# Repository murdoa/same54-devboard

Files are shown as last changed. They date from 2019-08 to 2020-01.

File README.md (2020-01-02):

# SAM-E54 Development Board
### Summary 
Development Board based around the Atmel SAME54 MCU exposing peripherals such as USB Host/Device, USB Serial, 100BASE-T Ethernet, SDHC and a QSPI with 1Gb flash.
### Features
- USB Host / Device
- USB Serial (CP2102) 
- SDHC Interface
- 100BASE-T Ethernet (KSZ8091RNA PHY)
- QSPI with W25N01GV footprint (1Gb flash)
- Cortex M ISP header
- 4 Indicator LEDs
- 3 Push Button switches
- 43 Pins accessible through 60 pin header

## Finished Board
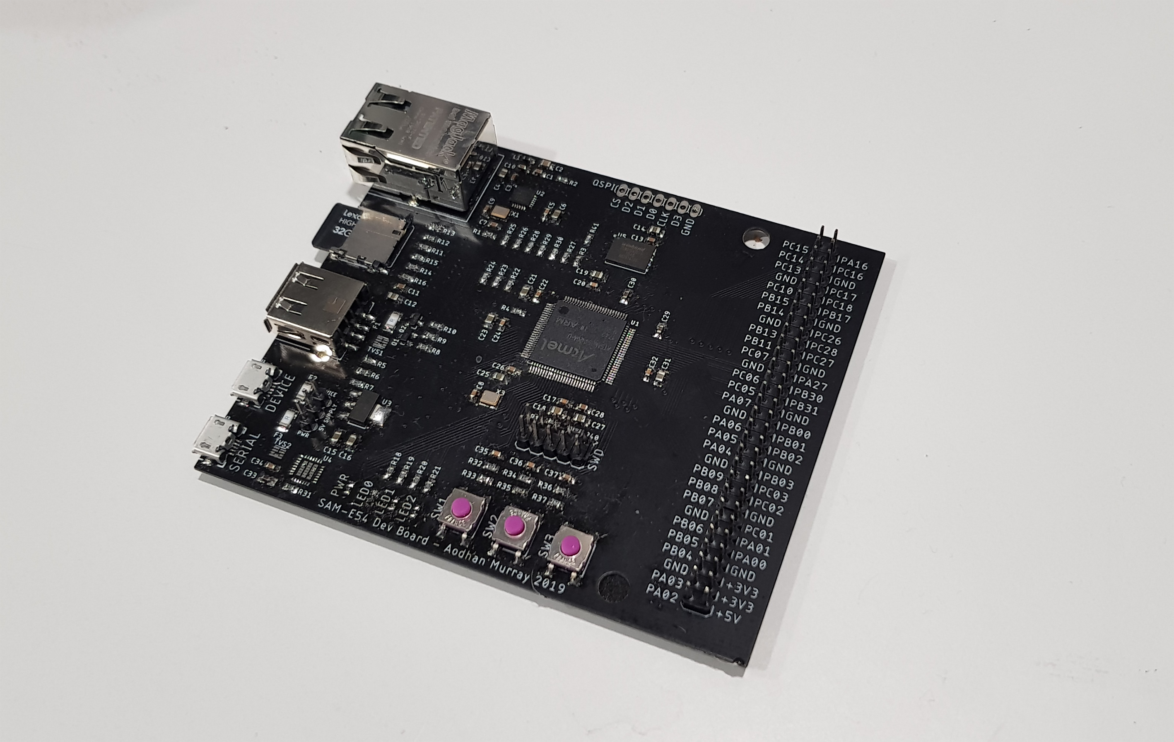
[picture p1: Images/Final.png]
Finished PCB Image


## PCB Stackup
| Layer | Material | Thickness |
|:-----:|:---:|:---:|
| 1 | Copper | 0.035mm |
|  | Prepreg | 0.2mm |
| 2 | Copper | 0.0175mm |
|  | Core | 0.265mm |
| 3 | Copper | 0.0175mm |
|  | Prepreg | 0.2mm |
| 4 | Copper | 0.035mm |

## Copper Layers
| Layer 1 | Layer 2 |
|:----:|:----:|
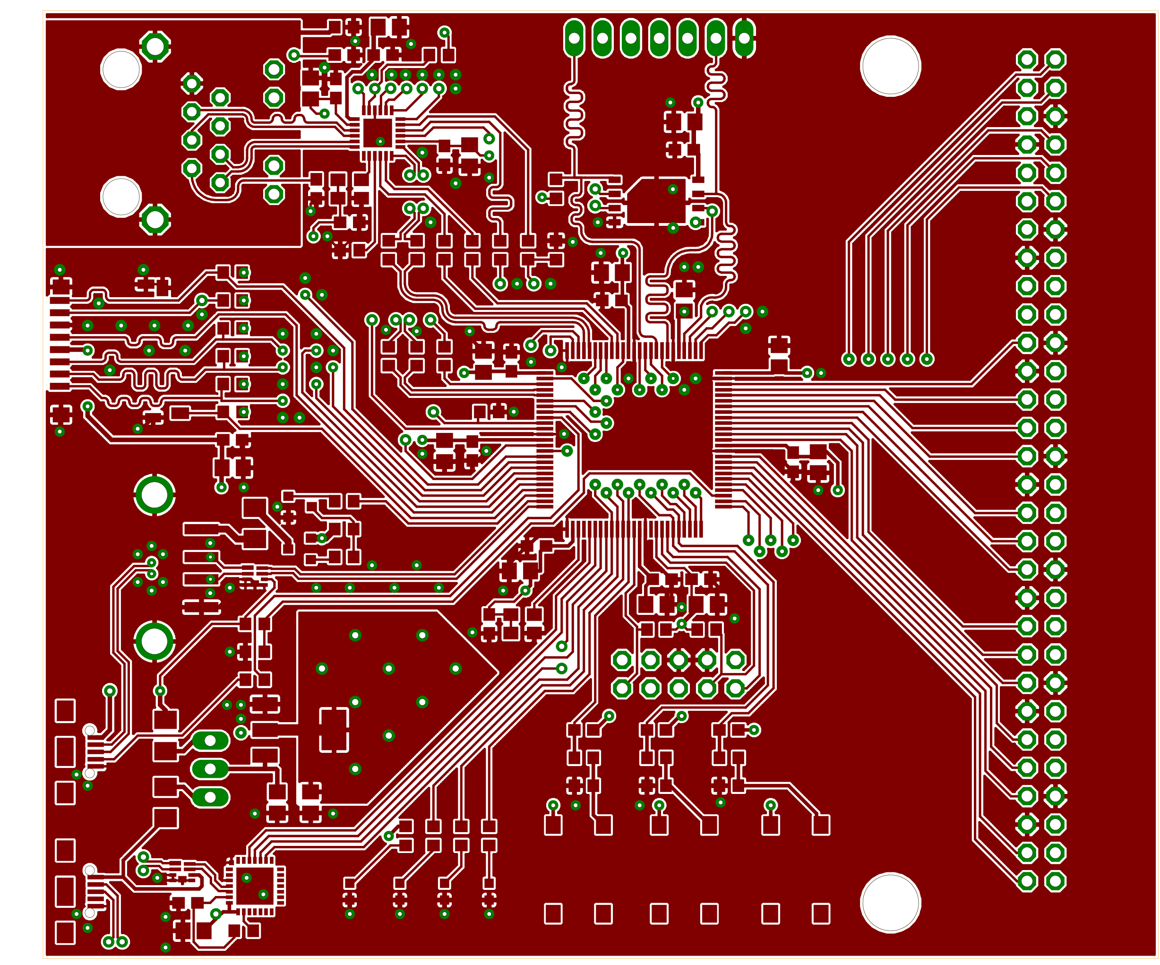
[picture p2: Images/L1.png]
Layer 1 Copper Image
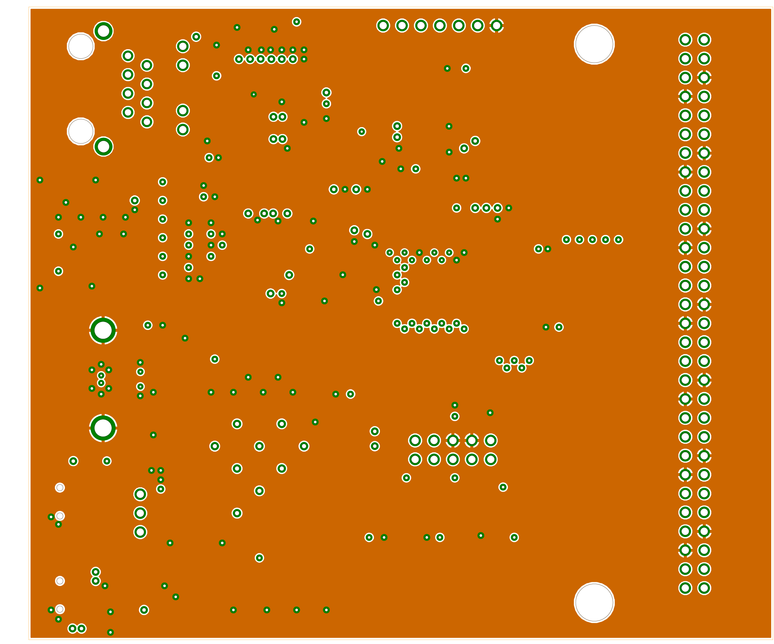
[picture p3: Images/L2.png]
Layer 2 Copper Image
||  |

| Layer 3 | Layer 4 |
|:----:|:----:|
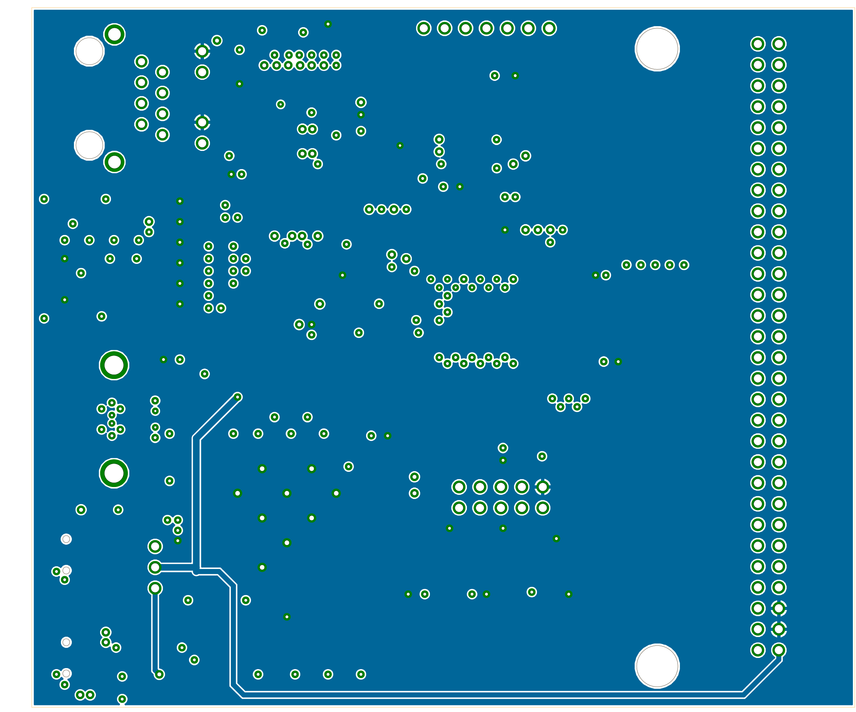
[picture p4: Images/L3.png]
Layer 3 Copper Image
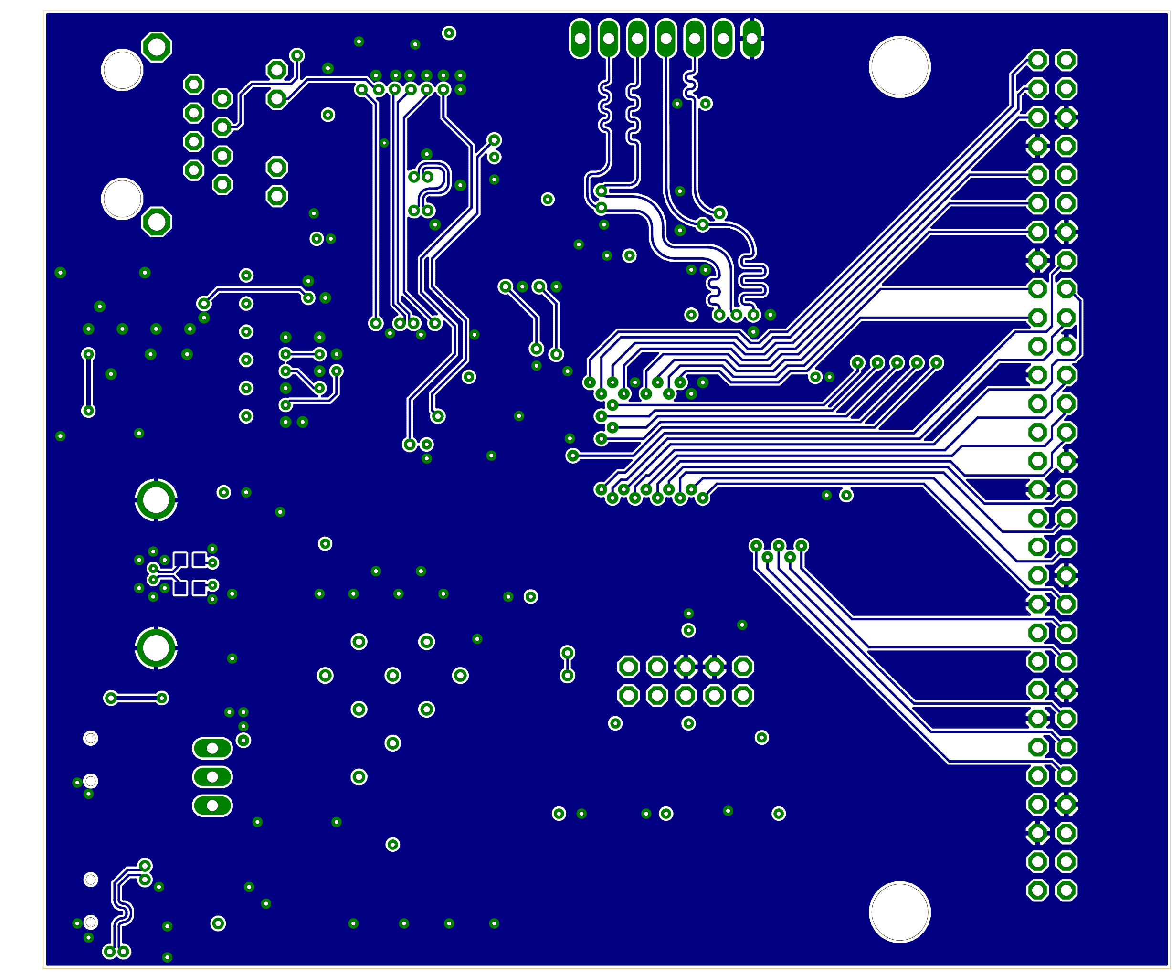
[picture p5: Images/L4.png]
Layer 4 Copper Image
||  |

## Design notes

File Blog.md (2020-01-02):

# ADS131E08 - Breakout

### Summary
Development Board based around the Atmel SAME54 MCU exposing peripherals such as USB Host/Device, USB Serial, 100BASE-T Ethernet, SDHC and a QSPI with 1Gb flash.

### Tags
 - EAGLE
 - Hardware Project
 - Development Board

### Images
 - [Images/Final.png] Final assembled PCB
 - [Images/FinishedDaughterBoard.png] Assembled ADC daughter board.

### Post 

### Features
- USB Host / Device
- USB Serial (CP2102) 
- SDHC Interface
- 100BASE-T Ethernet (KSZ8091RNA PHY)
- QSPI with W25N01GV footprint (1Gb flash)
- Cortex M ISP header
- 4 Indicator LEDs
- 3 Push Button switches
- 43 Pins accessible through 60 pin header

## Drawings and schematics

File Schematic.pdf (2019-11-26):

USB Power, ESD and OTG Host Detection | Push Buttons

# V_USB

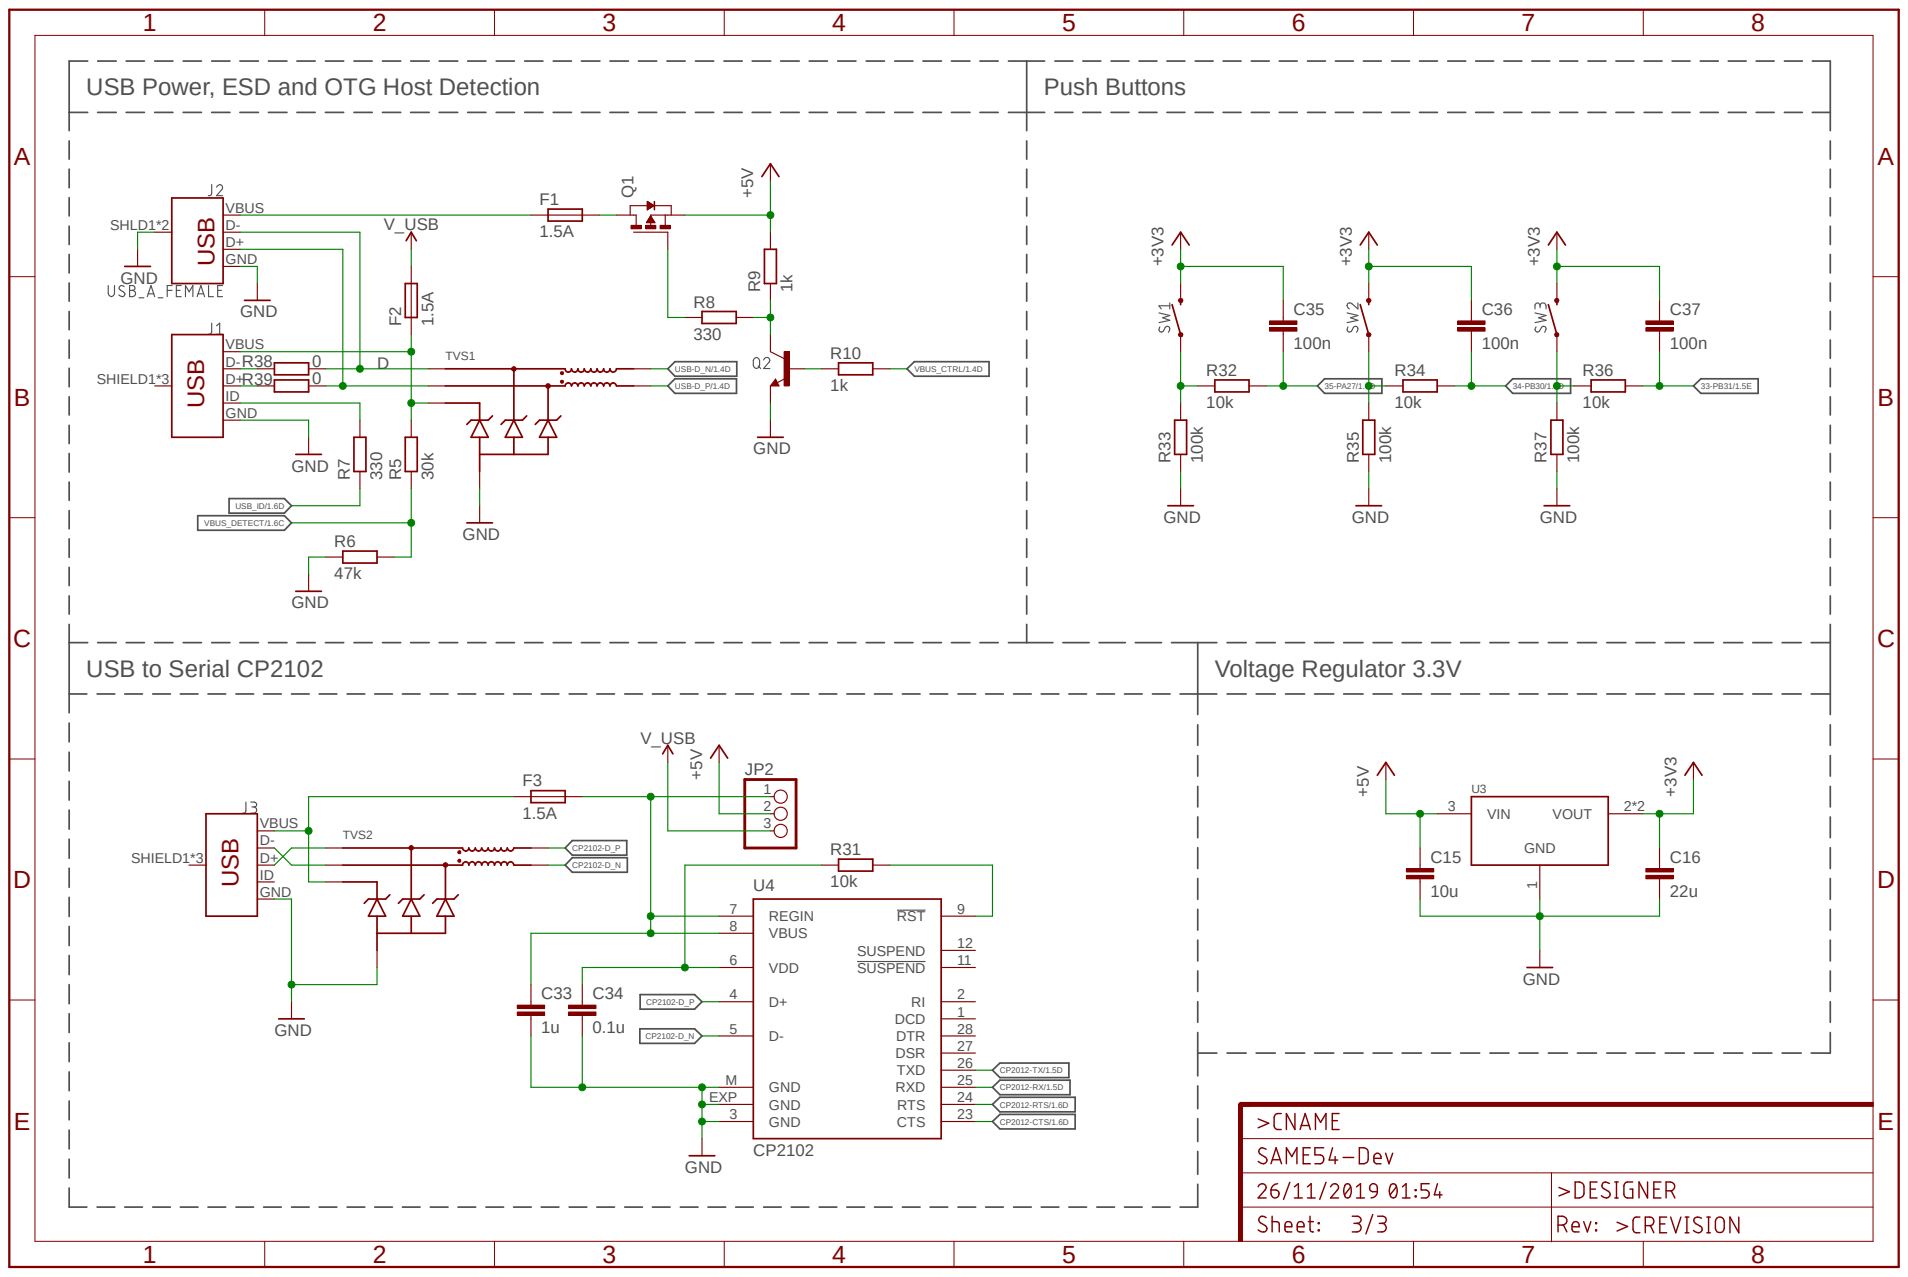
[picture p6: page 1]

CP2012-CTS/1.6D USB USB USB

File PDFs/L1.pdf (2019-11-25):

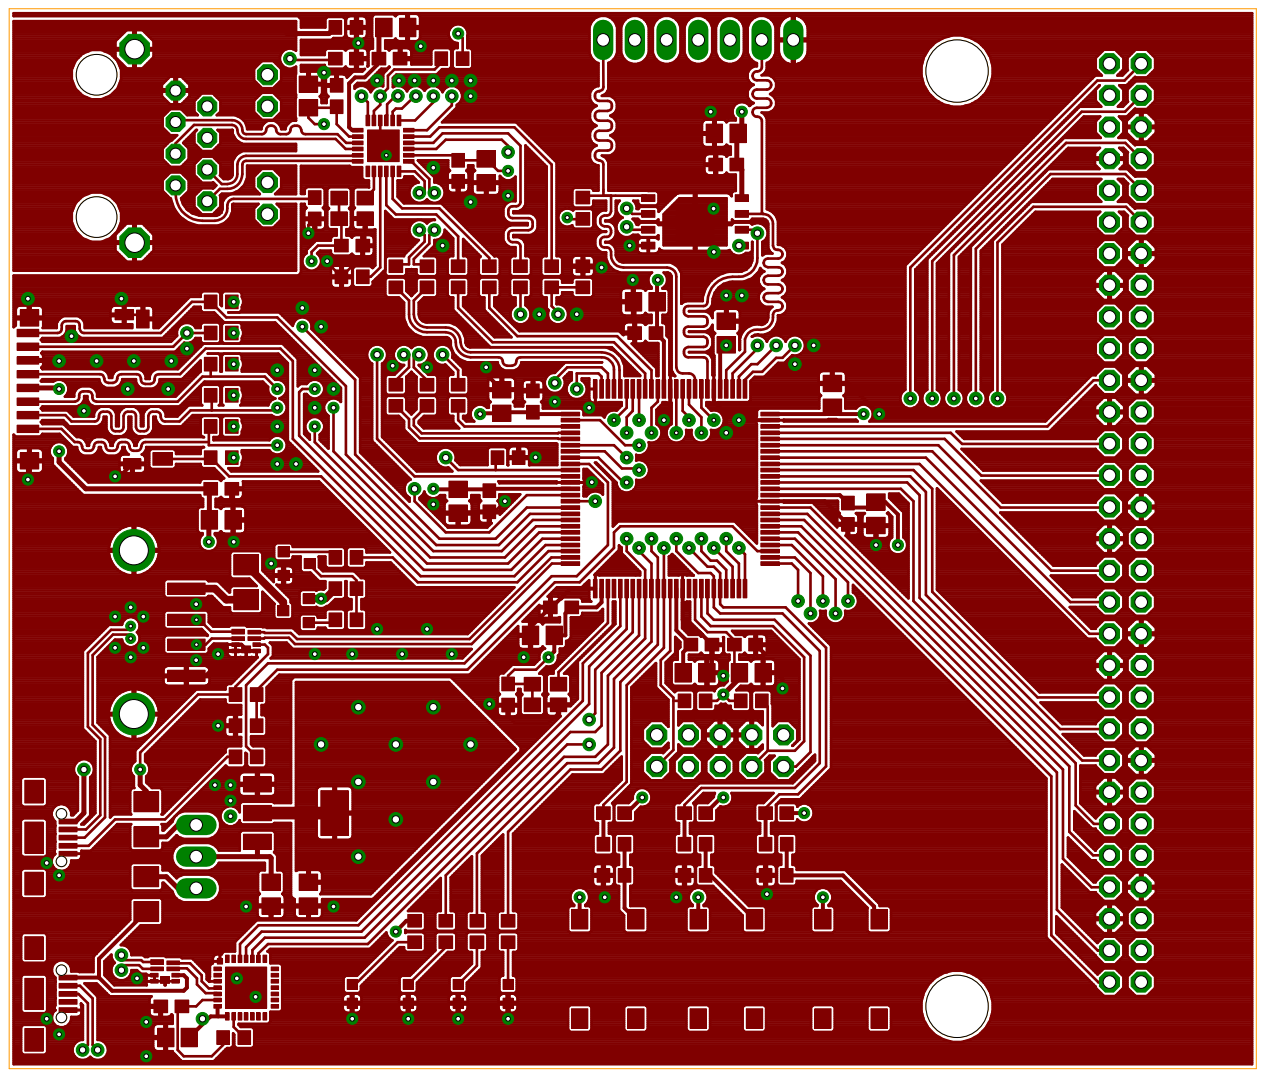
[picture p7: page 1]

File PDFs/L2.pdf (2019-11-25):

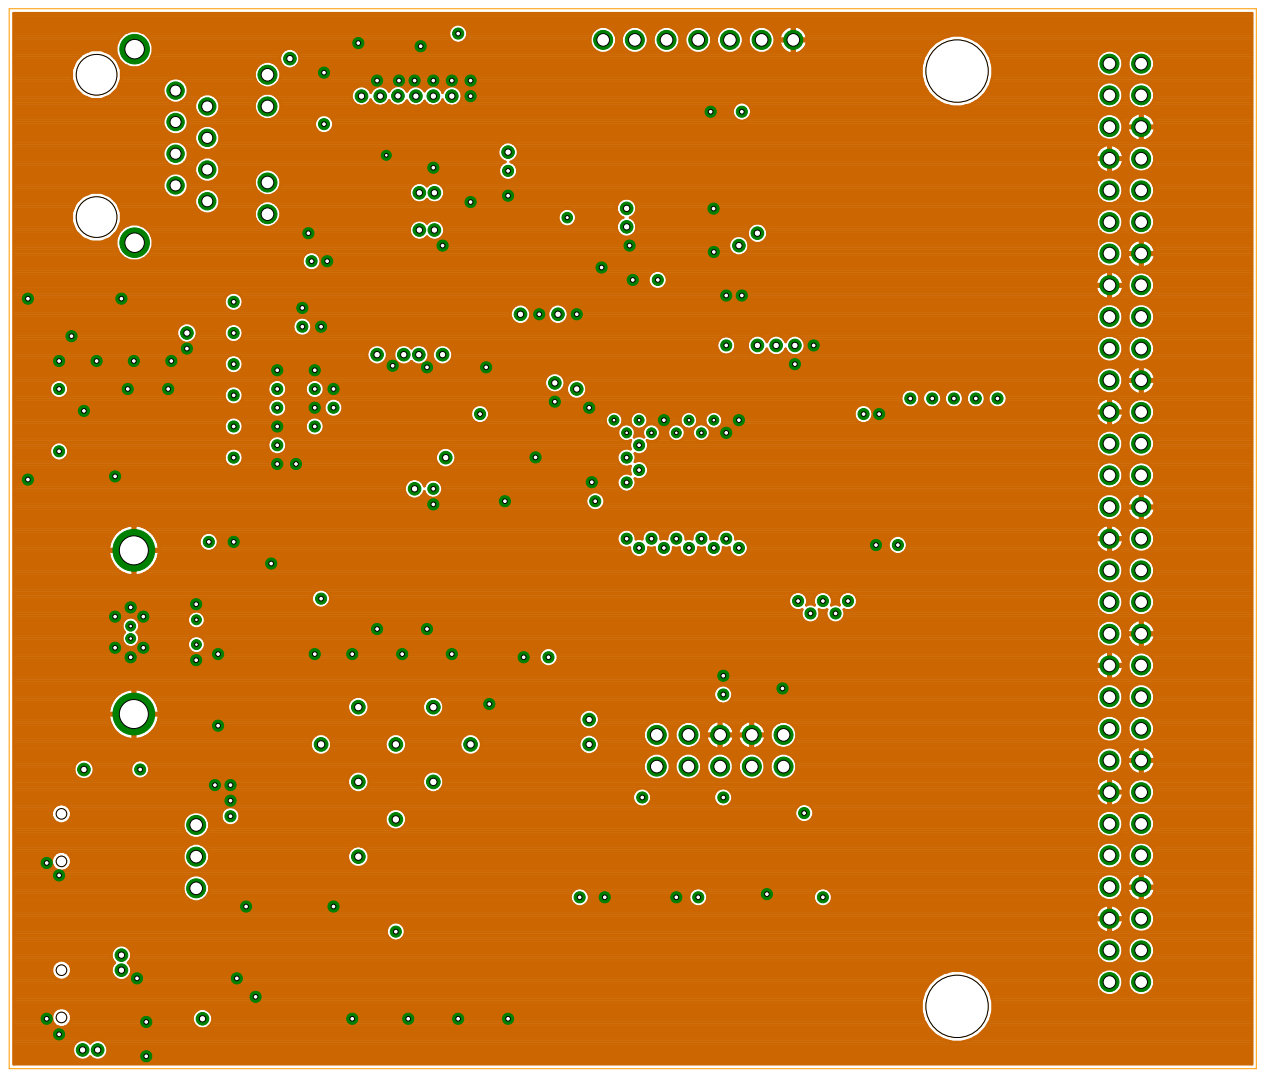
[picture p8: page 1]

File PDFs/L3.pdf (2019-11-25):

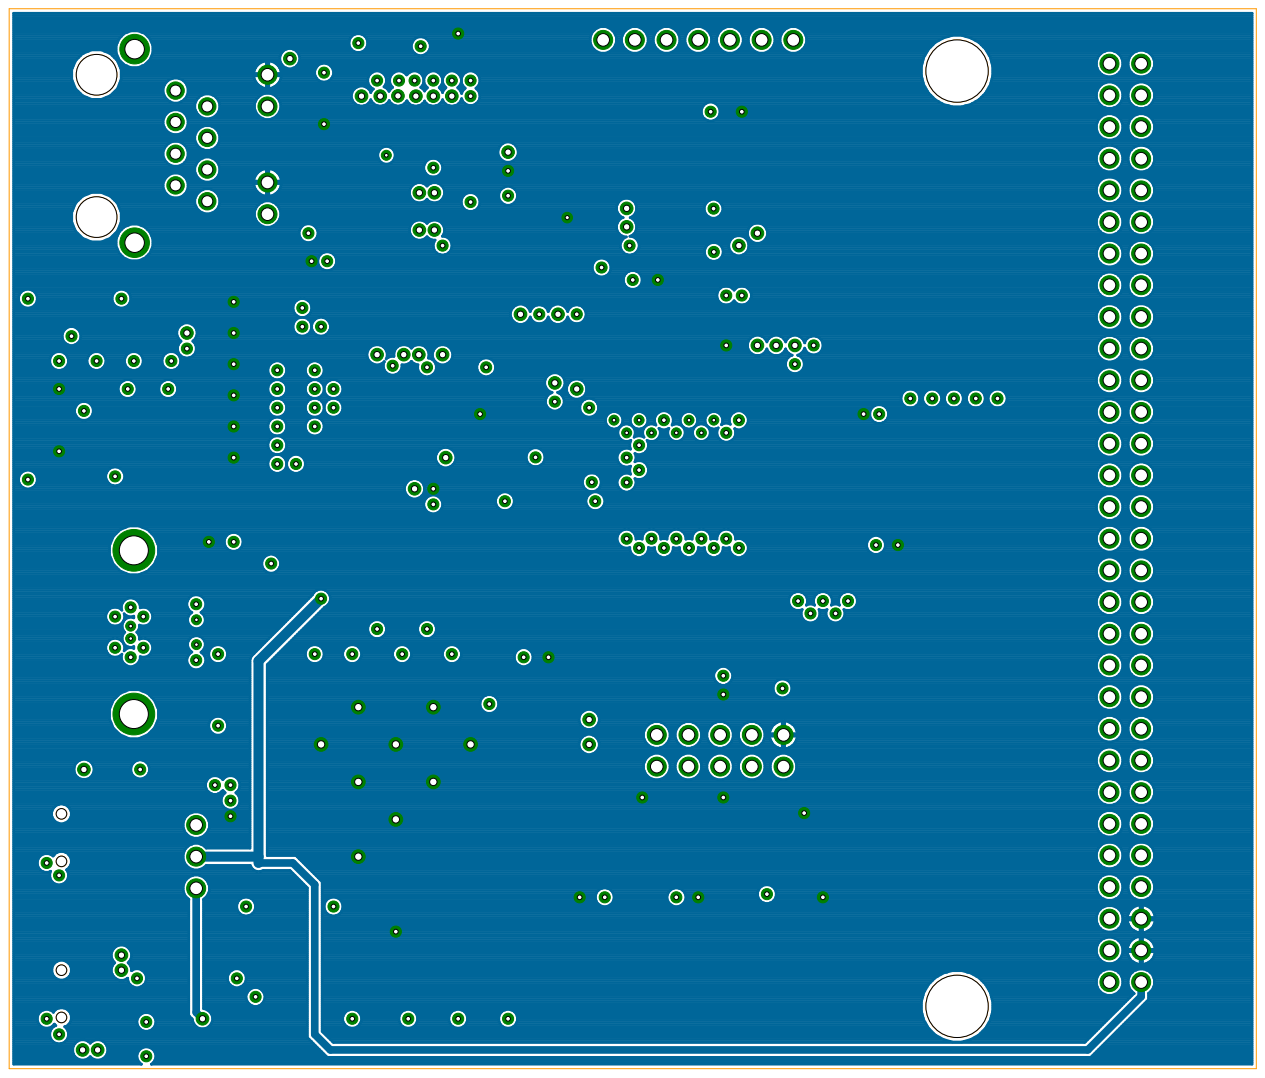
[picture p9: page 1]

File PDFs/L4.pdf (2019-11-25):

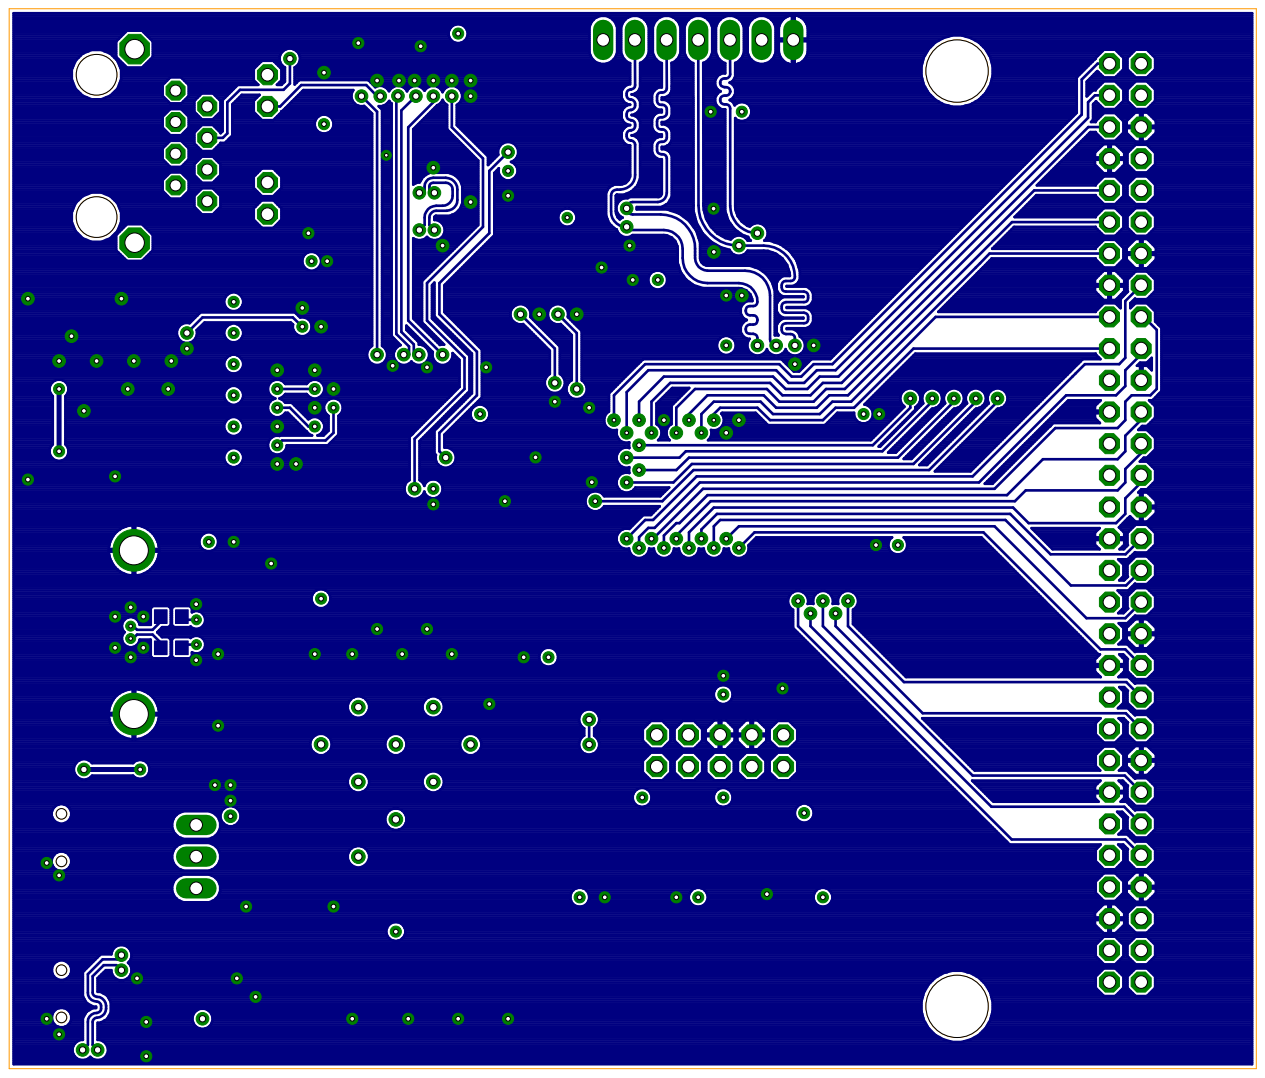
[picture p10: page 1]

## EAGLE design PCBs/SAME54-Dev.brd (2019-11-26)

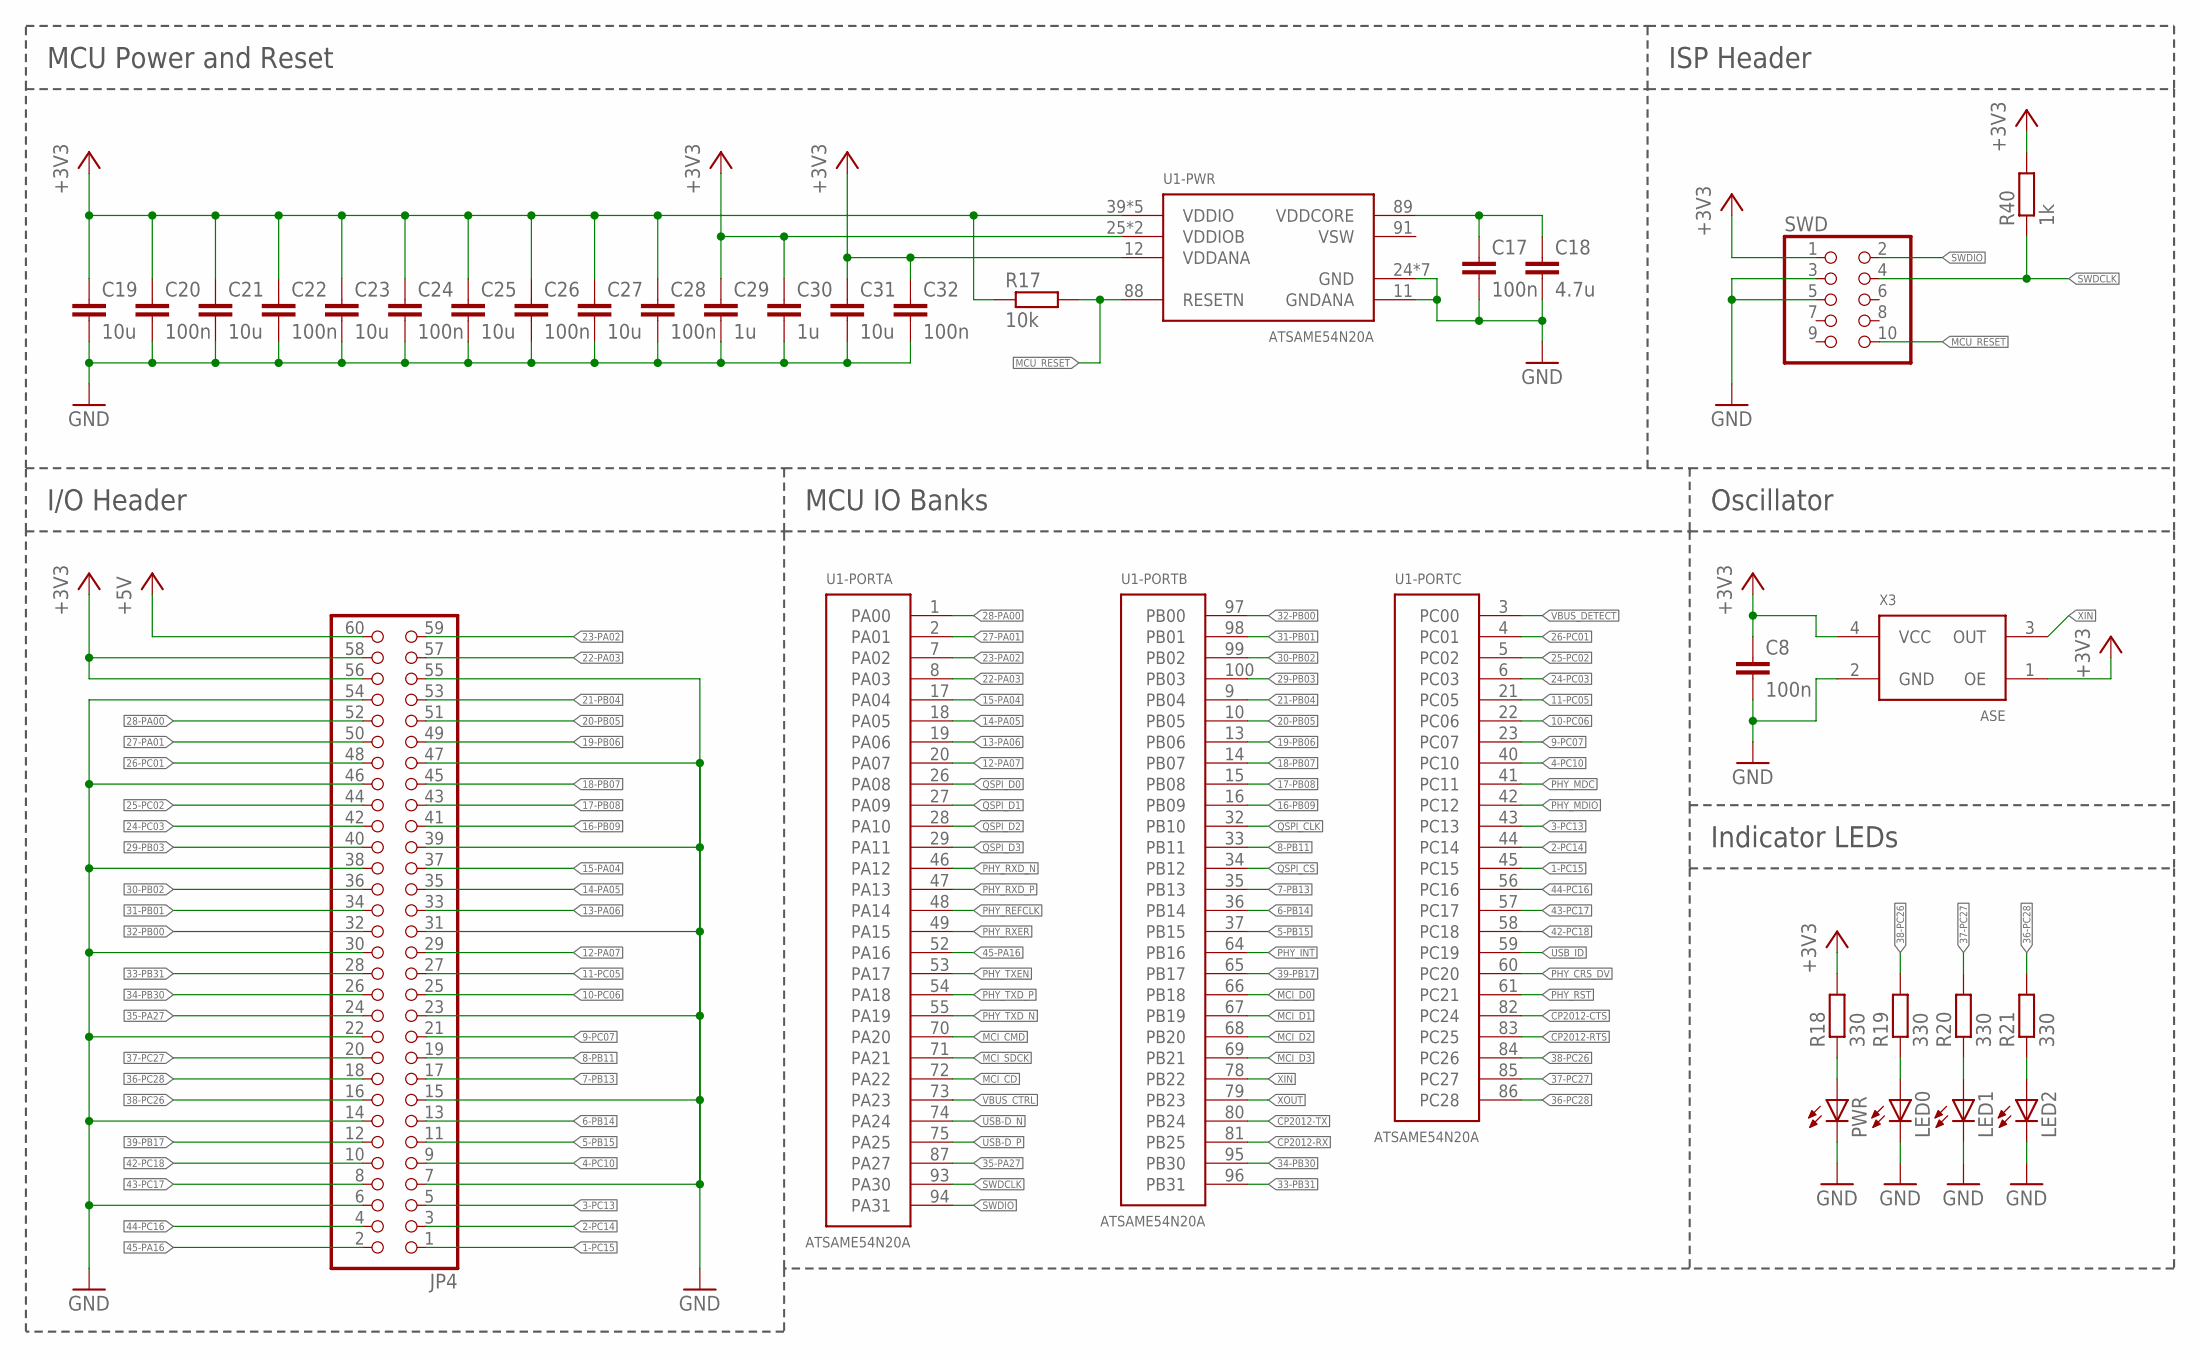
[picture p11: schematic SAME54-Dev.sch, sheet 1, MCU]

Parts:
C8, C17, C20, C22, C24, C26, C28, C32: 100n; C0603
C18: 4.7u; C0805
C19, C21, C23, C25, C27, C31: 10u; C0805
C29, C30: 1u; C0805
JP4: PINHD-2X30; 2X30
LED0, LED1, LED2: LEDCHIPLED_0603; CHIPLED_0603
PWR: LEDCHIPLED_0603; CHIPLED_0603
R17: 10k; R0603
R18, R19, R20, R21: 330; R0603
R40: 1k; R0603
SWD: PINHD-2X5; 2X05
U1: ATSAME54N20A; TQFP100
X3: ASE

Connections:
1-PC15: JP4.1, U1.45 (PC15)
2-PC14: JP4.3, U1.44 (PC14)
3-PC13: JP4.5, U1.43 (PC13)
4-PC10: JP4.9, U1.40 (PC10)
5-PB15: JP4.11, U1.37 (PB15)
6-PB14: JP4.13, U1.36 (PB14)
7-PB13: JP4.17, U1.35 (PB13)
8-PB11: JP4.19, U1.33 (PB11)
9-PC07: JP4.21, U1.23 (PC07)
10-PC06: JP4.25, U1.22 (PC06)
11-PC05: JP4.27, U1.21 (PC05)
12-PA07: JP4.29, U1.20 (PA07)
13-PA06: JP4.33, U1.19 (PA06)
14-PA05: JP4.35, U1.18 (PA05)
15-PA04: JP4.37, U1.17 (PA04)
16-PB09: JP4.41, U1.16 (PB09)
17-PB08: JP4.43, U1.15 (PB08)
18-PB07: JP4.45, U1.14 (PB07)
19-PB06: JP4.49, U1.13 (PB06)
20-PB05: JP4.51, U1.10 (PB05)
21-PB04: JP4.53, U1.9 (PB04)
22-PA03: JP4.57, U1.8 (PA03)
23-PA02: JP4.59, U1.7 (PA02)
24-PC03: JP4.42, U1.6 (PC03)
25-PC02: JP4.44, U1.5 (PC02)
26-PC01: JP4.48, U1.4 (PC01)
27-PA01: JP4.50, U1.2 (PA01)
28-PA00: JP4.52, U1.1 (PA00)
29-PB03: JP4.40, U1.100 (PB03)
30-PB02: JP4.36, U1.99 (PB02)
31-PB01: JP4.34, U1.98 (PB01)
32-PB00: JP4.32, U1.97 (PB00)
33-PB31: JP4.28, U1.96 (PB31); also elsewhere on the board
34-PB30: JP4.26, U1.95 (PB30); also elsewhere on the board
35-PA27: JP4.24, U1.87 (PA27); also elsewhere on the board
36-PC28: JP4.18, R21.2, U1.86 (PC28)
37-PC27: JP4.20, R20.2, U1.85 (PC27)
38-PC26: JP4.16, R19.2, U1.84 (PC26)
39-PB17: JP4.12, U1.65 (PB17)
42-PC18: JP4.10, U1.58 (PC18)
43-PC17: JP4.8, U1.57 (PC17)
44-PC16: JP4.4, U1.56 (PC16)
45-PA16: JP4.2, U1.52 (PA16)
+3V3: C8.1, C19.1, C20.1, C21.1, C22.1, C23.1, C24.1, C25.1, C26.1, C27.1, C28.1, C29.1, C30.1, C31.1, C32.1, JP4.56, JP4.58, R17.1, R18.2, R40.2, SWD.1, U1.12 (VDDANA), U1.25 (VDDIOB), U1.30 (VDDIOB), U1.39 (VDDIO), U1.51 (VDDIO), U1.63 (VDDIO), U1.77 (VDDIO), U1.92 (VDDIO), X3.1 (OE), X3.4 (VCC); also elsewhere on the board
+5V: JP4.60; also elsewhere on the board
CP2012-CTS: U1.82 (PC24); also elsewhere on the board
CP2012-RTS: U1.83 (PC25); also elsewhere on the board
CP2012-RX: U1.81 (PB25); also elsewhere on the board
CP2012-TX: U1.80 (PB24); also elsewhere on the board
GND: C8.2, C17.2, C18.2, C19.2, C20.2, C21.2, C22.2, C23.2, C24.2, C25.2, C26.2, C27.2, C28.2, C29.2, C30.2, C31.2, C32.2, JP4.6, JP4.7, JP4.14, JP4.15, JP4.22, JP4.23, JP4.30, JP4.31, JP4.38, JP4.39, JP4.46, JP4.47, JP4.54, JP4.55, LED0.C, LED1.C, LED2.C, PWR.C, SWD.3, SWD.5, U1.11 (GNDANA), U1.24 (GND), U1.31 (GND), U1.38 (GND), U1.50 (GND), U1.62 (GND), U1.76 (GND), U1.90 (GND), X3.2 (GND); also elsewhere on the board
MCI_CD: U1.72 (PA22); also elsewhere on the board
MCI_CMD: U1.70 (PA20); also elsewhere on the board
MCI_D0: U1.66 (PB18); also elsewhere on the board
MCI_D1: U1.67 (PB19); also elsewhere on the board
MCI_D2: U1.68 (PB20); also elsewhere on the board
MCI_D3: U1.69 (PB21); also elsewhere on the board
MCI_SDCK: U1.71 (PA21); also elsewhere on the board
MCU_RESET: R17.2, SWD.10, U1.88 (RESETN)
unnamed: PWR.A, R18.1
unnamed: LED0.A, R19.1
unnamed: C17.1, C18.1, U1.89 (VDDCORE)
unnamed: LED1.A, R20.1
unnamed: LED2.A, R21.1
PHY_CRS_DV: U1.60 (PC20); also elsewhere on the board
PHY_INT: U1.64 (PB16); also elsewhere on the board
PHY_MDC: U1.41 (PC11); also elsewhere on the board
PHY_MDIO: U1.42 (PC12); also elsewhere on the board
PHY_REFCLK: U1.48 (PA14); also elsewhere on the board
PHY_RST: U1.61 (PC21); also elsewhere on the board
PHY_RXD_N: U1.46 (PA12); also elsewhere on the board
PHY_RXD_P: U1.47 (PA13); also elsewhere on the board
PHY_RXER: U1.49 (PA15); also elsewhere on the board
PHY_TXD_N: U1.55 (PA19); also elsewhere on the board
PHY_TXD_P: U1.54 (PA18); also elsewhere on the board
PHY_TXEN: U1.53 (PA17); also elsewhere on the board
QSPI_CLK: U1.32 (PB10); also elsewhere on the board
QSPI_CS: U1.34 (PB12); also elsewhere on the board
QSPI_D0: U1.26 (PA08); also elsewhere on the board
QSPI_D1: U1.27 (PA09); also elsewhere on the board
QSPI_D2: U1.28 (PA10); also elsewhere on the board
QSPI_D3: U1.29 (PA11); also elsewhere on the board
SWDCLK: R40.1, SWD.4, U1.93 (PA30)
SWDIO: SWD.2, U1.94 (PA31)
USB-D_N: U1.74 (PA24); also elsewhere on the board
USB-D_P: U1.75 (PA25); also elsewhere on the board
USB_ID: U1.59 (PC19); also elsewhere on the board
VBUS_CTRL: U1.73 (PA23); also elsewhere on the board
VBUS_DETECT: U1.3 (PC00); also elsewhere on the board
XIN: U1.78 (PB22), X3.3 (OUT)
XOUT: U1.79 (PB23)

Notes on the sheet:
MCU Power and Reset
MCU IO Banks
I/O Header
ISP Header
Indicator LEDs
Oscillator

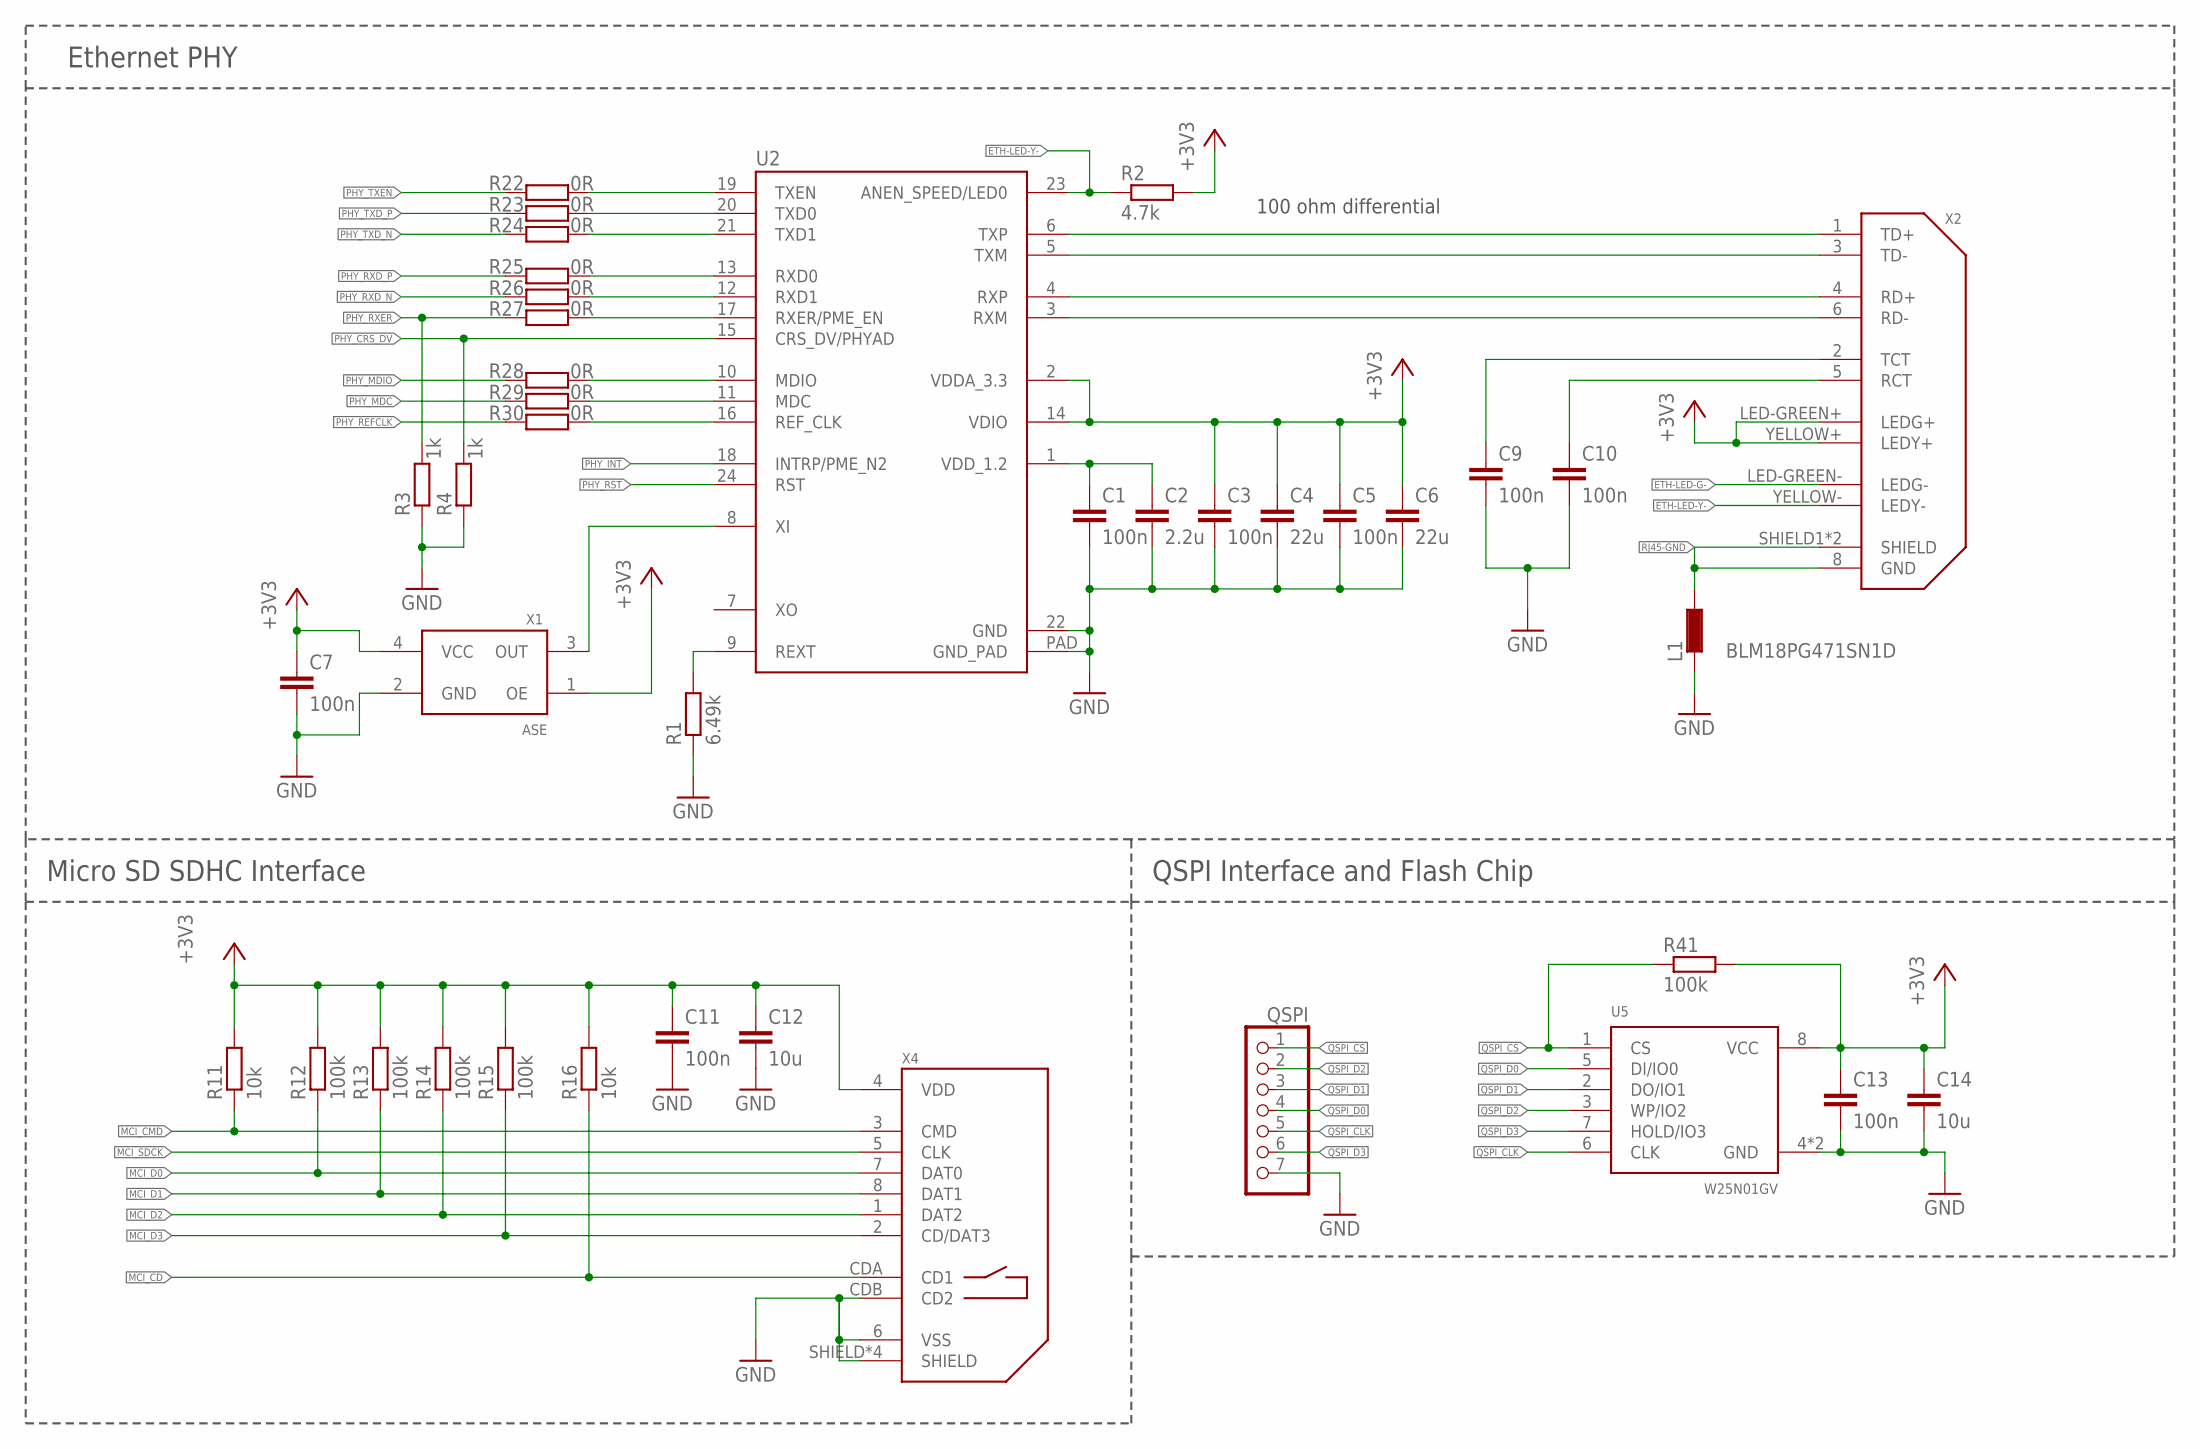
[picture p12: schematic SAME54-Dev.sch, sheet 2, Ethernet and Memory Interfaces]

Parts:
C1, C3, C5, C7, C9, C10, C11, C13: 100n; C0603
C2: 2.2u; C0805
C4, C6: 22u; C0805
C12, C14: 10u; C0805
L1: BLM18PG471SN1D; R0603
QSPI: PINHD-1X7; 1X07
R1: 6.49k; R0603
R2: 4.7k; R0603
R3, R4: 1k; R0603
R11, R16: 10k; R0603
R12, R13, R14, R15, R41: 100k; R0603
R22, R23, R24, R25, R26, R27, R28, R29, R30: 0R; R0603
U2: KSZ8091RNA; QFN24
U5: W25N01GV; WSON8
X1: ASE
X2: SI-50170-F
X4: DM3D-SF

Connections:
+3V3: C3.1, C4.1, C5.1, C6.1, C7.1, C11.1, C12.1, C13.1, C14.1, R2.2, R11.2, R12.2, R13.2, R14.2, R15.2, R16.2, R41.2, U2.2 (VDDA_3.3), U2.14 (VDIO), U5.8 (VCC), X1.1 (OE), X1.4 (VCC), X2.LED-GREEN+ (LEDG+), X2.YELLOW+ (LEDY+), X4.4 (VDD); also elsewhere on the board
ETH-LED-G-: X2.LED-GREEN- (LEDG-)
ETH-LED-Y-: R2.1, U2.23 (ANEN_SPEED/LED0), X2.YELLOW- (LEDY-)
GND: C1.2, C2.2, C3.2, C4.2, C5.2, C6.2, C7.2, C9.2, C10.2, C11.2, C12.2, C13.2, C14.2, L1.1, QSPI.7, R1.1, R3.1, R4.1, U2.22 (GND), U2.PAD (GND_PAD), U5.4 (GND), U5.PAD (GND), X1.2 (GND), X4.6 (VSS), X4.CDB (CD2), X4.SHIELD, X4.SHIELD1 (SHIELD), X4.SHIELD2 (SHIELD), X4.SHIELD3 (SHIELD); also elsewhere on the board
MCI_CD: R16.1, X4.CDA (CD1); also elsewhere on the board
MCI_CMD: R11.1, X4.3 (CMD); also elsewhere on the board
MCI_D0: R12.1, X4.7 (DAT0); also elsewhere on the board
MCI_D1: R13.1, X4.8 (DAT1); also elsewhere on the board
MCI_D2: R14.1, X4.1 (DAT2); also elsewhere on the board
MCI_D3: R15.1, X4.2 (CD/DAT3); also elsewhere on the board
MCI_SDCK: X4.5 (CLK); also elsewhere on the board
unnamed: U2.8 (XI), X1.3 (OUT)
unnamed: C9.1, X2.2 (TCT)
unnamed: C10.1, X2.5 (RCT)
unnamed: R1.2, U2.9 (REXT)
unnamed: C1.1, C2.1, U2.1 (VDD_1.2)
PHY_CRS_DV: R4.2, U2.15 (CRS_DV/PHYAD); also elsewhere on the board
PHY_INT: U2.18 (INTRP/PME_N2); also elsewhere on the board
PHY_MDC: R29.1; also elsewhere on the board
PHY_MDIO: R28.1; also elsewhere on the board
PHY_PIN_MDC: R29.2, U2.11 (MDC)
PHY_PIN_MDIO: R28.2, U2.10 (MDIO)
PHY_PIN_REFCLK: R30.2, U2.16 (REF_CLK)
PHY_PIN_RXD_N: R26.2, U2.12 (RXD1)
PHY_PIN_RXD_P: R25.2, U2.13 (RXD0)
PHY_PIN_RXER: R27.2, U2.17 (RXER/PME_EN)
PHY_PIN_TXD_N: R24.2, U2.21 (TXD1)
PHY_PIN_TXD_P: R23.2, U2.20 (TXD0)
PHY_PIN_TXEN: R22.2, U2.19 (TXEN)
PHY_REFCLK: R30.1; also elsewhere on the board
PHY_RST: U2.24 (RST); also elsewhere on the board
PHY_RXD_N: R26.1; also elsewhere on the board
PHY_RXD_P: R25.1; also elsewhere on the board
PHY_RXER: R3.2, R27.1; also elsewhere on the board
PHY_TXD_N: R24.1; also elsewhere on the board
PHY_TXD_P: R23.1; also elsewhere on the board
PHY_TXEN: R22.1; also elsewhere on the board
QSPI_CLK: QSPI.5, U5.6 (CLK); also elsewhere on the board
QSPI_CS: QSPI.1, R41.1, U5.1 (CS); also elsewhere on the board
QSPI_D0: QSPI.4, U5.5 (DI/IO0); also elsewhere on the board
QSPI_D1: QSPI.3, U5.2 (DO/IO1); also elsewhere on the board
QSPI_D2: QSPI.2, U5.3 (WP/IO2); also elsewhere on the board
QSPI_D3: QSPI.6, U5.7 (HOLD/IO3); also elsewhere on the board
RJ45-GND: L1.2, X2.8 (GND), X2.SHIELD1 (SHIELD), X2.SHIELD2 (SHIELD)
RX_N: U2.3 (RXM), X2.6 (RD-)
RX_P: U2.4 (RXP), X2.4 (RD+)
TX_N: U2.5 (TXM), X2.3 (TD-)
TX_P: U2.6 (TXP), X2.1 (TD+)

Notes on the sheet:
100 ohm differential
Ethernet PHY
Micro SD SDHC Interface
QSPI Interface and Flash Chip

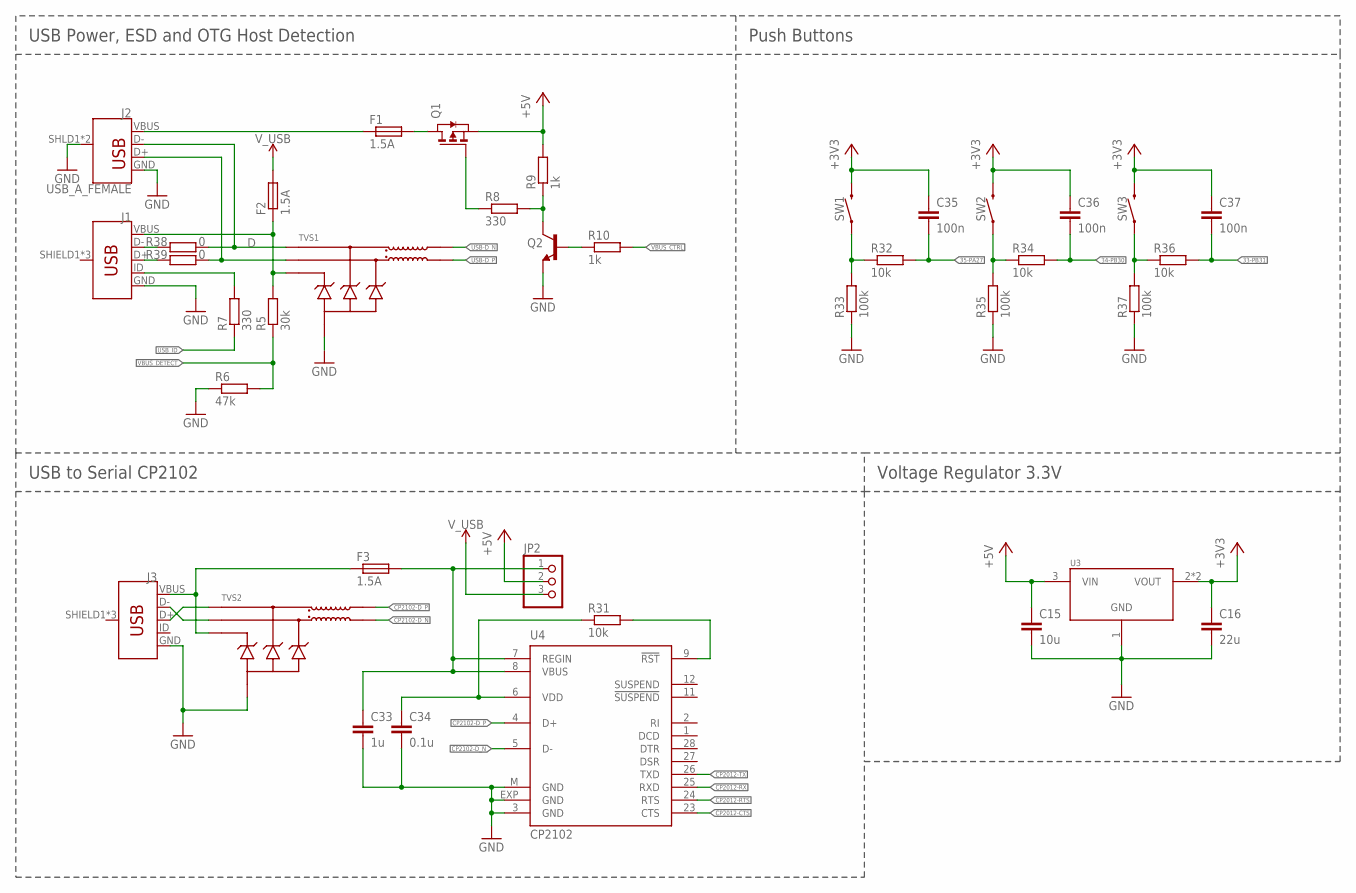
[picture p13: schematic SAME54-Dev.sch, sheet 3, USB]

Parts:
C15: 10u; C0805
C16: 22u; C0805
C33: 1u; C0805
C34: 0.1u; C0603
C35, C36, C37: 100n; C0603
F1, F2, F3: 1.5A; M1206
J1, J3: USB_MICRO-BREDUCED_PASTE; USB-B-MICRO-SMD_RED_PASTE
J2: USB_A_FEMALE; USB-A-S-SILK-FEMALE
JP2: PINHD-1X3; 1X03
Q1: PMOSSOT23; SOT-23
Q2: TRANS_NPN-MMBTA42; SOT23-3
R5: 30k; R0603
R6: 47k; R0603
R7, R8: 330; R0603
R9, R10: 1k; R0603
R31, R32, R34, R36: 10k; R0603
R33, R35, R37: 100k; R0603
R38, R39: 0; R0603
SW1, SW2, SW3: MOMENTARY-SWITCH-SPST-SMD-6.2MM-TALL; TACTILE_SWITCH_SMD_6.2MM_TALL
TVS1, TVS2: EMI2121MT; WDFN8
U3: AP1117; SOT223
U4: CP2102; MLP28

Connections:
33-PB31: C37.2, R36.2; also elsewhere on the board
34-PB30: C36.2, R34.2; also elsewhere on the board
35-PA27: C35.2, R32.2; also elsewhere on the board
+3V3: C16.1, C35.1, C36.1, C37.1, SW1.B2 (2), SW2.B2 (2), SW3.B2 (2), U3.2 (VOUT), U3.4 (VOUT); also elsewhere on the board
+5V: C15.1, JP2.2, Q1.2 (S), R9.2, U3.3 (VIN); also elsewhere on the board
CP2012-CTS: U4.23 (CTS); also elsewhere on the board
CP2012-RTS: U4.24 (RTS); also elsewhere on the board
CP2012-RX: U4.25 (RXD); also elsewhere on the board
CP2012-TX: U4.26 (TXD); also elsewhere on the board
CP2102-D_N: TVS2.7, U4.5 (D-)
CP2102-D_P: TVS2.8, U4.4 (D+)
D: J2.D-, R38.2, TVS1.1
D_P: J2.D+, R39.2, TVS1.2
GND: C15.2, C16.2, C33.2, C34.2, J1.GND, J2.GND, J2.SHLD1 (SHIELD), J2.SHLD2 (SHIELD), J3.GND, Q2.2 (E), R6.1, R33.1, R35.1, R37.1, TVS1.3 (3,4,5), TVS1.4 (3,4,5), TVS1.5 (3,4,5), TVS1.PAD (3,4,5), TVS2.3 (3,4,5), TVS2.4 (3,4,5), TVS2.5 (3,4,5), TVS2.PAD (3,4,5), U3.1 (GND), U4.3 (GND), U4.EXP (GND), U4.M (GND); also elsewhere on the board
unnamed: F1.1, J2.VBUS
unnamed: F1.2, Q1.1 (D)
unnamed: F2.1, J1.VBUS, R5.2, TVS1.6
unnamed: F3.1, J3.VBUS, TVS2.6
unnamed: C34.1, R31.1, U4.6 (VDD)
unnamed: C33.1, F3.2, JP2.1, U4.7 (REGIN), U4.8 (VBUS)
unnamed: Q1.3 (G), R8.1
unnamed: Q2.3 (C), R8.2, R9.1
unnamed: Q2.1 (B), R10.1
unnamed: R31.2, U4.9 (!RST)
unnamed: R32.1, R33.2, SW1.A2 (1)
unnamed: R34.1, R35.2, SW2.A2 (1)
unnamed: R36.1, R37.2, SW3.A2 (1)
PRE-TVS-D_N: J3.D-, TVS2.2
PRE-TVS-D_P: J3.D+, TVS2.1
USB-D_N: TVS1.8; also elsewhere on the board
USB-D_P: TVS1.7; also elsewhere on the board
USB_DEV_N: J1.D-, R38.1
USB_DEV_P: J1.D+, R39.1
USB_ID: R7.1; also elsewhere on the board
VBUS_CTRL: R10.2; also elsewhere on the board
VBUS_DETECT: R5.1, R6.2; also elsewhere on the board
VBUS_HOST_EN: J1.ID, R7.2
V_USB: F2.2, JP2.3

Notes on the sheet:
Push Buttons
USB Power, ESD and OTG Host Detection
USB to Serial CP2102
Voltage Regulator 3.3V

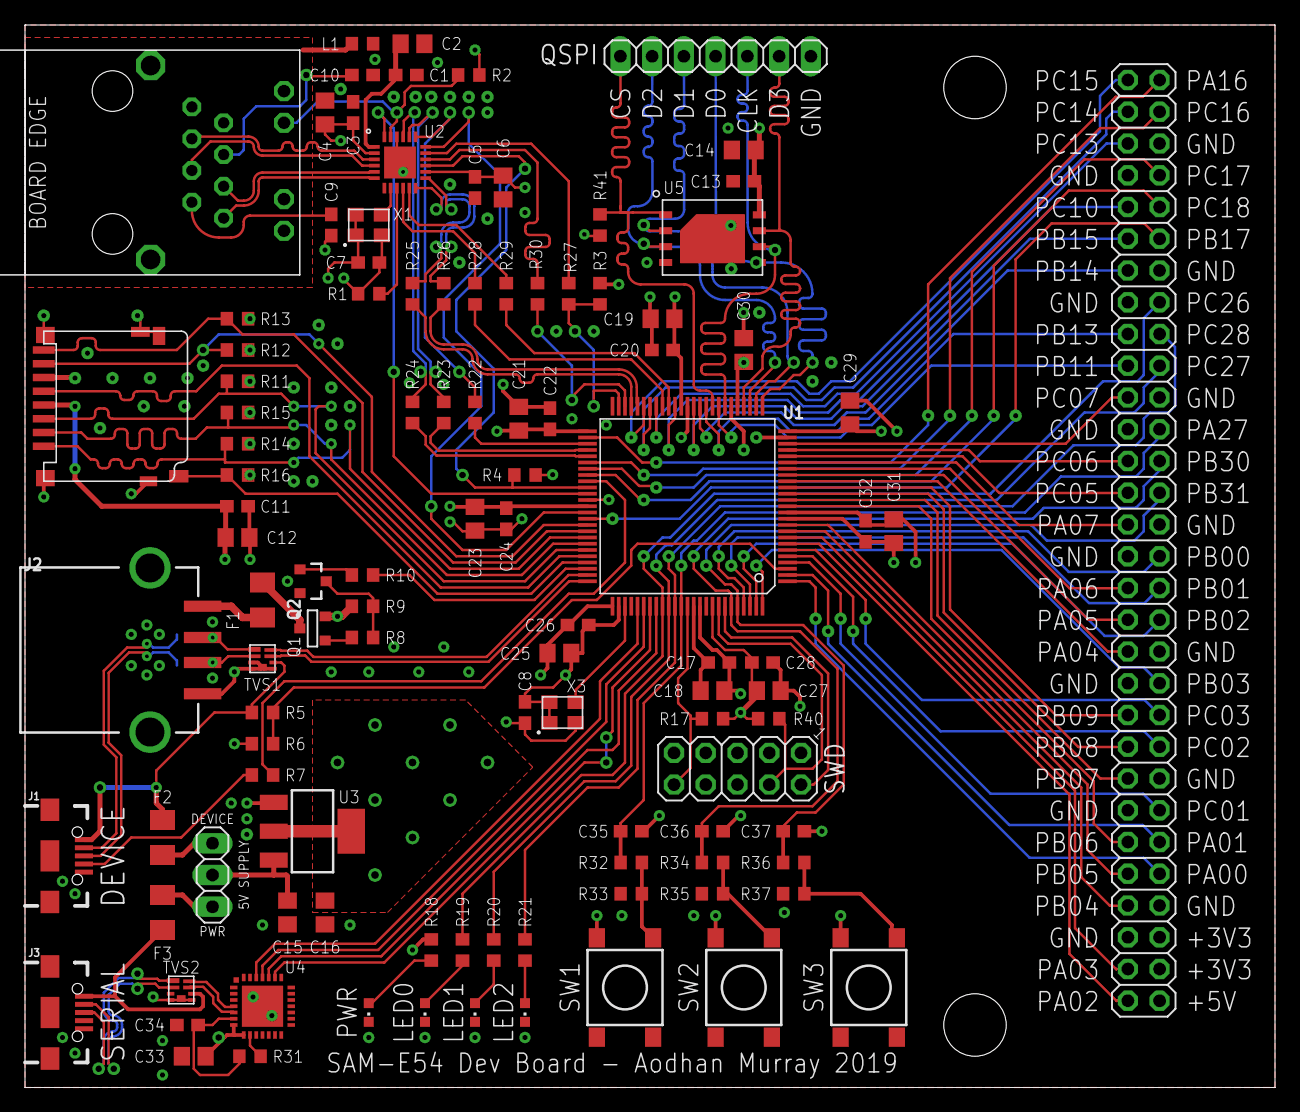
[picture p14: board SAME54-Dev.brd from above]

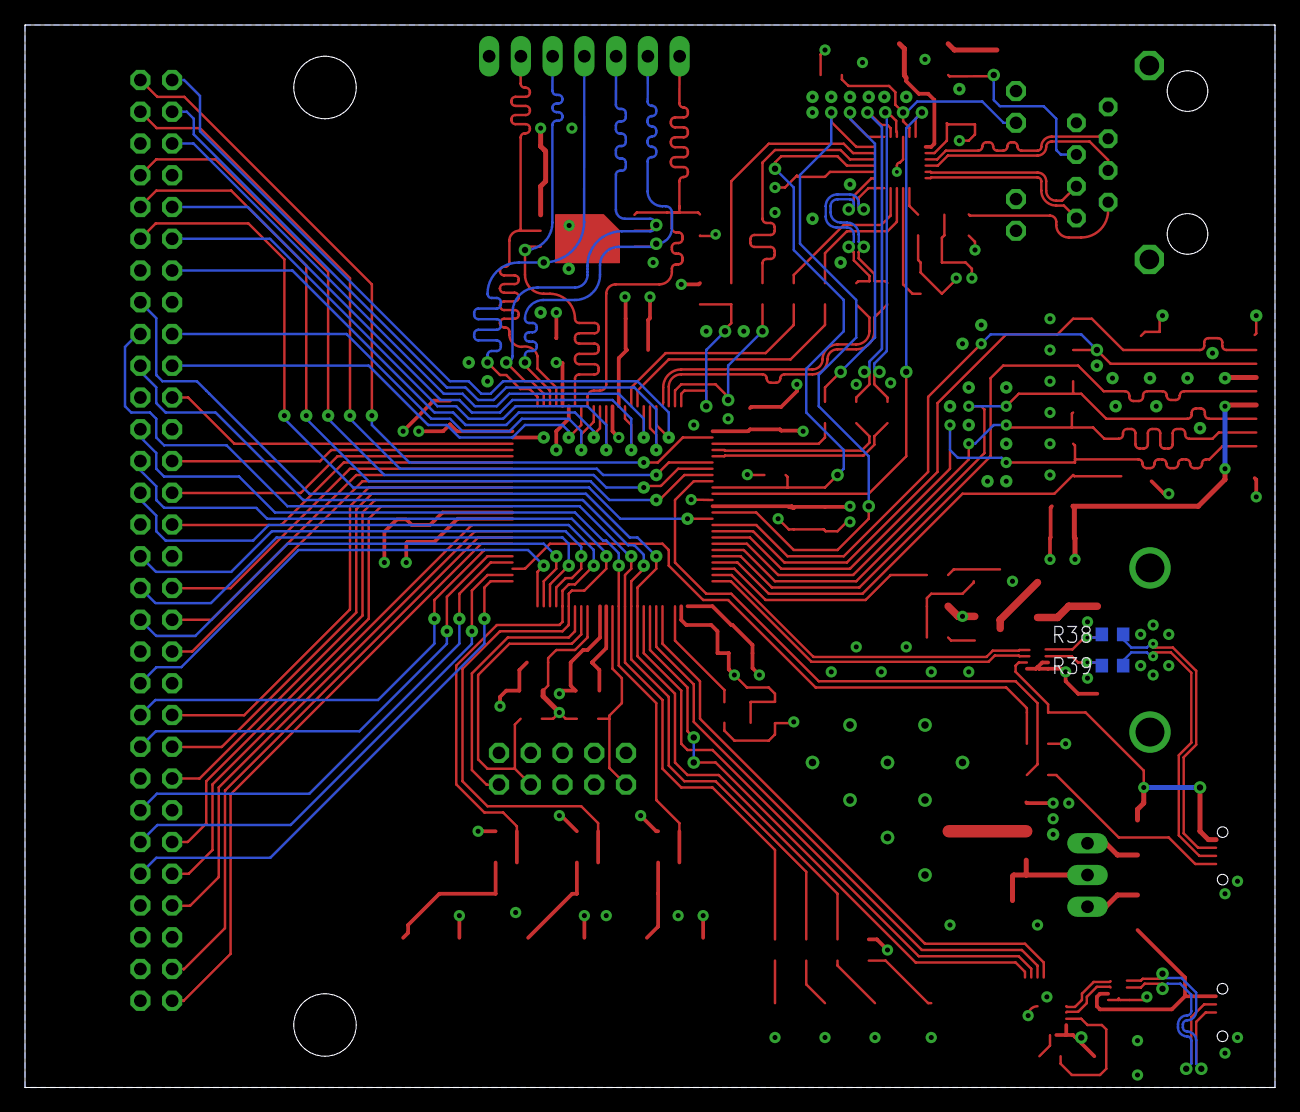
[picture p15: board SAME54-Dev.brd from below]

Board: 4 copper layers, 100.0 x 85.0 mm, 109 parts (2 on the bottom side), 132 nets.

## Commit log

2019-08-05 created repo
    [SAME54-Dev.brd, SAME54-Dev.sch]
2019-11-25 Restructured project.
    [SAME54-Dev.brd, SAME54-Dev.sch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]
2019-11-25 Added images of copper layers and finished board
2019-11-26 Added schematic PDF
    [SAME54-Dev.brd, SAME54-Dev.sch]

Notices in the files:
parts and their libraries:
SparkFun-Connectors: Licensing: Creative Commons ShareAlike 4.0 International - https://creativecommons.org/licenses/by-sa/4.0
